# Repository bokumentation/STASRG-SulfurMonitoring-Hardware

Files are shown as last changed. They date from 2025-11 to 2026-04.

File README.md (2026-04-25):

# Init Main Branch

clone this repo with the submodules

```
git clone --recursive https://github.com/bokumentation/STASRG-SulfurMonitoring-Hardware.git
```

## to-do-list

- memisahkan firmware dari repo ini
    - receiver
    - transmitter
    - dummy-uart
- membuat repo sendiri libs untuk kicad dan dibuat submodules

# ghostl + ESP32-S3: The `-mtext-section-literals` Fix

## The Problem

Building ESP-IDF projects that use `ghostl` (via `espsoftwareserial`) for **ESP32-S3** fails with:

```
dangerous relocation: l32r: literal placed after use: .literal._ZNK8delegate...
```

This error **does not** occur on:
- **ESP32** (Xtensa LX6)
- **ESP32-C3** (RISC-V)

And it **does not** occur when building the same code with **Arduino IDE** (arduino-esp32).

## Root Cause

### The `l32r` instruction

The Xtensa architecture has a `l32r` (load literal from PC-relative) instruction used to load 32-bit constants. It loads a value from a **literal pool** — a table of constants placed at a known offset from the current PC. The range of `l32r` is approximately ±256 KB from the instruction.

### IRAM vs Flash on ESP32-S3

Functions marked with `IRAM_ATTR` (as many are in `Delegate.h` and `SoftwareSerial`) are placed in **IRAM** (internal RAM, address range 0x4037xxxx). The normal code (.text) is placed in **flash** (mapped to 0x4200xxxx).

Without `-mtext-section-literals`:
- The compiler places all literal pools in a **centralized .literal section** that lives alongside the flash code (0x4200xxxx)
- Functions in IRAM emit `l32r` instructions pointing to the .literal section in flash
- The distance between IRAM (0x4037xxxx) and the literal pool in flash (0x4200xxxx) exceeds the `l32r` addressing range
- The linker rejects this as a **dangerous relocation**

### Why ESP32 (LX6) is fine

ESP32 uses Xtensa LX6 which defaults to **`-mtext-section-literals` being enabled** in ESP-IDF. So the literal pool is placed inside each text section — no cross-section addressing issue.

### Why ESP32-C3 (RISC-V) is fine

ESP32-C3 is RISC-V, not Xtensa. It has no `l32r` instruction — it uses a different instruction encoding for loading constants. The issue is Xtensa-specific.

### Why Arduino IDE is fine

Arduino IDE (arduino-esp32) sets compile flags differently than ESP-IDF. In particular, it passes `-mtext-section-literals` by default in its platform configuration, avoiding the problem entirely. This is why the same source code that fails in ESP-IDF works in Arduino without any modifications.

## The Fix: `-mtext-section-literals`

Add this to the `CMakeLists.txt` of any component that depends on `ghostl` (e.g. `espsoftwareserial`):

```cmake
target_compile_options(${COMPONENT_LIB} PRIVATE -mtext-section-literals)
```

### How it works

The `-mtext-section-literals` flag tells the Xtensa compiler to place each function's literal pool **inside that function's own text section**, rather than in a centralized `.literal` section. Since the function is in IRAM, its literals go to IRAM too — well within `l32r` range.

### Is it safe?

**Yes, it is completely safe:**

| Concern | Assessment |
|---|---|
| Runtime behavior | No functional change. Literals are read-only constants — being in IRAM vs flash makes no difference to program correctness. |
| Performance | No impact. Constants are read the same way via cache at full speed. |
| IRAM / ISR usage | Preserved. All `IRAM_ATTR` functions continue to work correctly in interrupt context. |
| Binary size | Minor increase (typically < 1 KB). Literal pools may be duplicated across functions instead of shared, but this is negligible. |
| Espressif recommendation | Standard practice. Used by default on ESP32 and in Arduino-esp32. |

## The Previous Attempt: Removing `IRAM_ATTR`

### What we tried

We removed `IRAM_ATTR` from the `operator()` methods in `DelegatePImpl` and `DelegateImpl` classes (the `std::function`/`FUNC` path) in `Delegate.h`.

### Why it worked

Without `IRAM_ATTR`, those functions are placed in flash (0x4200xxxx), right next to the centralized `.literal` section. The `l32r` instruction can reach the literal pool fine — same section, same address space.

### Why we reverted it

Removing `IRAM_ATTR` means those functions **cannot be called from ISR context** — a fundamental requirement for software serial implementations where UART callbacks happen in interrupt context. The `FP` and `FPA` dispatch paths (raw function pointers) retained `IRAM_ATTR`, but the `std::function` path lost ISR safety.

### The better solution

Instead of modifying source code (and compromising ISR safety), we use `-mtext-section-literals` which requires **zero source changes**. All dispatch paths keep their `IRAM_ATTR`, all functions stay ISR-safe, and the linker error is resolved at the compiler flag level.

## Summary

| Build Environment | Default `-mtext-section-literals` | Builds? |
|---|---|---|
| ESP-IDF + ESP32 | ✅ Yes (default) | ✅ |
| ESP-IDF + ESP32-C3 | N/A (RISC-V, no l32r) | ✅ |
| ESP-IDF + ESP32-S3 | ❌ No (default) | ❌ Fails |
| Arduino IDE + ESP32-S3 | ✅ Yes (in platform config) | ✅ |

The fix: add `-mtext-section-literals` to the consumer component's CMakeLists.txt. No source code changes needed.

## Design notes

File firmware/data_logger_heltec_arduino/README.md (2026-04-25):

# Sensor Montoring by STAS-RG
Supported Target: ESP32 | ESP32C3 | ESP32S3

## Daftar Variabel
Tinggal dilanjutkan:

```
live_data.so2_ugm, 
live_data.h2s_ugm, 
live_data.h2s_temp, 
live_data.h2s_hum,
live_data.wind_speed, 
live_data.bus_voltage_v, 
live_data.current_ma
```

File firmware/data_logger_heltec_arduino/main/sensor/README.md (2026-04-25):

Original Example Code from Vendor

```cpp
// anemometer parameters
volatile byte rpmcount;             // hitung signals
volatile unsigned long last_micros;

unsigned long timeold;
unsigned long timemeasure = 10.00;  // detik
int timetoSleep = 1;                // menit
unsigned long sleepTime = 15;       // menit
unsigned long timeNow;
int countThing = 0;
int GPIO_pulse = 14;                // ESP32 = D14
float rpm, rotasi_per_detik;        // rotasi/detik
float kecepatan_kilometer_per_jam;  // kilometer/jam
float kecepatan_meter_per_detik;    //meter/detik
volatile boolean flag = false;

void ICACHE_RAM_ATTR rpm_anemometer()
{
  flag = true;
}

void setup()
{
  pinMode(GPIO_pulse, INPUT_PULLUP);
  digitalWrite(GPIO_pulse, LOW);
  Serial.begin(9600);
  detachInterrupt(digitalPinToInterrupt(GPIO_pulse));                         // memulai Interrupt pada nol
  attachInterrupt(digitalPinToInterrupt(GPIO_pulse), rpm_anemometer, RISING); //Inisialisasi pin interupt
  rpmcount = 0;
  rpm = 0;
  timeold = 0;
  timeNow = 0;
} // end of setup

void loop()
{
  // Cek apakah flag bernilai true, yang menandakan bahwa kondisi tertentu telah terpenuhi
  if (flag == true)
  {
    // Cek apakah waktu sejak deteksi terakhir sudah lebih dari atau sama dengan 5000 mikrodetik (5 milidetik)
    if (long(micros() - last_micros) >= 5000)
    {
      // rJika ya, maka tambahkan satu ke penghitung rpm (pmcount)
      rpmcount++;
      // Perbarui waktu terakhir ketika magnet terdeteksi dengan waktu saat ini
      last_micros = micros();
    }
    // Setelah memproses, setel flag kembali ke false untuk menandakan bahwa kondisi telah ditangani
    flag = false; // reset flag
  }

  if ((millis() - timeold) >= timemeasure * 1000)
  {
    countThing++;
    detachInterrupt(digitalPinToInterrupt(GPIO_pulse));      // Menonaktifkan interrupt saat menghitung
    rotasi_per_detik = float(rpmcount) / float(timemeasure); // rotasi per detik
    //kecepatan_meter_per_detik = rotasi_per_detik; // rotasi/detik sebelum dikalibrasi untuk dijadikan meter per detik
    kecepatan_meter_per_detik = ((-0.0181 * (rotasi_per_detik * rotasi_per_detik)) + (1.3859 * rotasi_per_detik) + 1.4055); // meter/detik sesudah dikalibrasi dan sudah dijadikan meter per detik
    if (kecepatan_meter_per_detik <= 1.5)
    { // Minimum pembacaan sensor kecepatan angin adalah 1.5 meter/detik
      kecepatan_meter_per_detik = 0.0;
    }

    kecepatan_kilometer_per_jam = kecepatan_meter_per_detik * 3.6; // kilometer/jam
    Serial.print("rotasi_per_detik=");
    Serial.print(rotasi_per_detik);
    Serial.print("   kecepatan_meter_per_detik="); // Minimal kecepatan angin yang dapat dibaca sensor adalah 4 meter/detik dan maksimum 30 meter/detik.
    Serial.print(kecepatan_meter_per_detik);
    Serial.print("   kecepatan_kilometer_per_jam=");
    Serial.print(kecepatan_kilometer_per_jam);
    Serial.println("   ");

    if (countThing == 1) // kirim data per 10 detik sekali
    {
      Serial.println("Mengirim data ke server");
      countThing = 0;
    }
    timeold = millis();
    rpmcount = 0;
    attachInterrupt(digitalPinToInterrupt(GPIO_pulse), rpm_anemometer, RISING); // enable interrupt
  }
} // end of loop

```

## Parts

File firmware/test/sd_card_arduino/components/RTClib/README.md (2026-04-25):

# RTClib Documentation

This is a fork of JeeLab's fantastic real time clock library for Arduino.

Works great with Adafruit RTC breakouts:

- [DS3231 Precision RTC](https://www.adafruit.com/product/3013) (breakout) and [Stemma QT version](https://www.adafruit.com/product/5188)
- [PCF8523 RTC](https://www.adafruit.com/product/3295)
- [DS1307 RTC](https://www.adafruit.com/product/3296)

Please note that dayOfTheWeek() ranges from 0 to 6 inclusive with 0 being 'Sunday'.

<!-- START COMPATIBILITY TABLE -->

## Compatibility

MCU                | Tested Works | Doesn't Work | Not Tested  | Notes
------------------ | :----------: | :----------: | :---------: | -----
Atmega328 @ 16MHz  |      X       |             |            |
Atmega328 @ 12MHz  |      X       |             |            |
Atmega32u4 @ 16MHz |      X       |             |            | Use SDA/SCL on pins D3 &amp; D2
Atmega32u4 @ 8MHz  |      X       |             |            | Use SDA/SCL on pins D3 &amp; D2
ESP8266            |      X       |             |            | SDA/SCL default to pins 4 &amp; 5 but any two pins can be assigned as SDA/SCL using Wire.begin(SDA,SCL)
Atmega2560 @ 16MHz |      X       |             |            | Use SDA/SCL on Pins 20 &amp; 21
ATSAM3X8E          |      X       |             |            | Use SDA1 and SCL1
ATSAM21D           |      X       |             |            |
ATtiny85 @ 16MHz   |      X       |             |            |
ATtiny85 @ 8MHz    |      X       |             |            |
Intel Curie @ 32MHz |             |             |     X       |
STM32F2            |             |             |     X       |

  * ATmega328 @ 16MHz : Arduino UNO, Adafruit Pro Trinket 5V, Adafruit Metro 328, Adafruit Metro Mini
  * ATmega328 @ 12MHz : Adafruit Pro Trinket 3V
  * ATmega32u4 @ 16MHz : Arduino Leonardo, Arduino Micro, Arduino Yun, Teensy 2.0
  * ATmega32u4 @ 8MHz : Adafruit Flora, Bluefruit Micro
  * ESP8266 : Adafruit Huzzah
  * ATmega2560 @ 16MHz : Arduino Mega
  * ATSAM3X8E : Arduino Due
  * ATSAM21D : Arduino Zero, M0 Pro
  * ATtiny85 @ 16MHz : Adafruit Trinket 5V
  * ATtiny85 @ 8MHz : Adafruit Gemma, Arduino Gemma, Adafruit Trinket 3V

<!-- END COMPATIBILITY TABLE -->
Adafruit invests time and resources providing this open source code, please support Adafruit and open-source hardware by purchasing products from Adafruit!

# Dependencies
 * [Adafruit BusIO](https://github.com/adafruit/Adafruit_BusIO)

# Contributing

Contributions are welcome! Please read our [Code of Conduct](https://github.com/adafruit/RTClib/blob/master/code-of-conduct.md)
before contributing to help this project stay welcoming.

## Documentation and doxygen
For the detailed API documentation, see https://adafruit.github.io/RTClib/html/index.html
Documentation is produced by doxygen. Contributions should include documentation for any new code added.

Some examples of how to use doxygen can be found in these guide pages:

https://learn.adafruit.com/the-well-automated-arduino-library/doxygen

https://learn.adafruit.com/the-well-automated-arduino-library/doxygen-tips

## Code formatting and clang-format
The code should be formatted according to the [LLVM Coding Standards](https://llvm.org/docs/CodingStandards.html), which is the default of the clang-format tool.  The easiest way to ensure conformance is to [install clang-format](https://llvm.org/builds/) and run

```shell
clang-format -i <source_file>
```

See [Formatting with clang-format](https://learn.adafruit.com/the-well-automated-arduino-library/formatting-with-clang-format) for details.

Written by JeeLabs
MIT license, check license.txt for more information
All text above must be included in any redistribution

To install, use the Arduino Library Manager and search for "RTClib" and install the library.

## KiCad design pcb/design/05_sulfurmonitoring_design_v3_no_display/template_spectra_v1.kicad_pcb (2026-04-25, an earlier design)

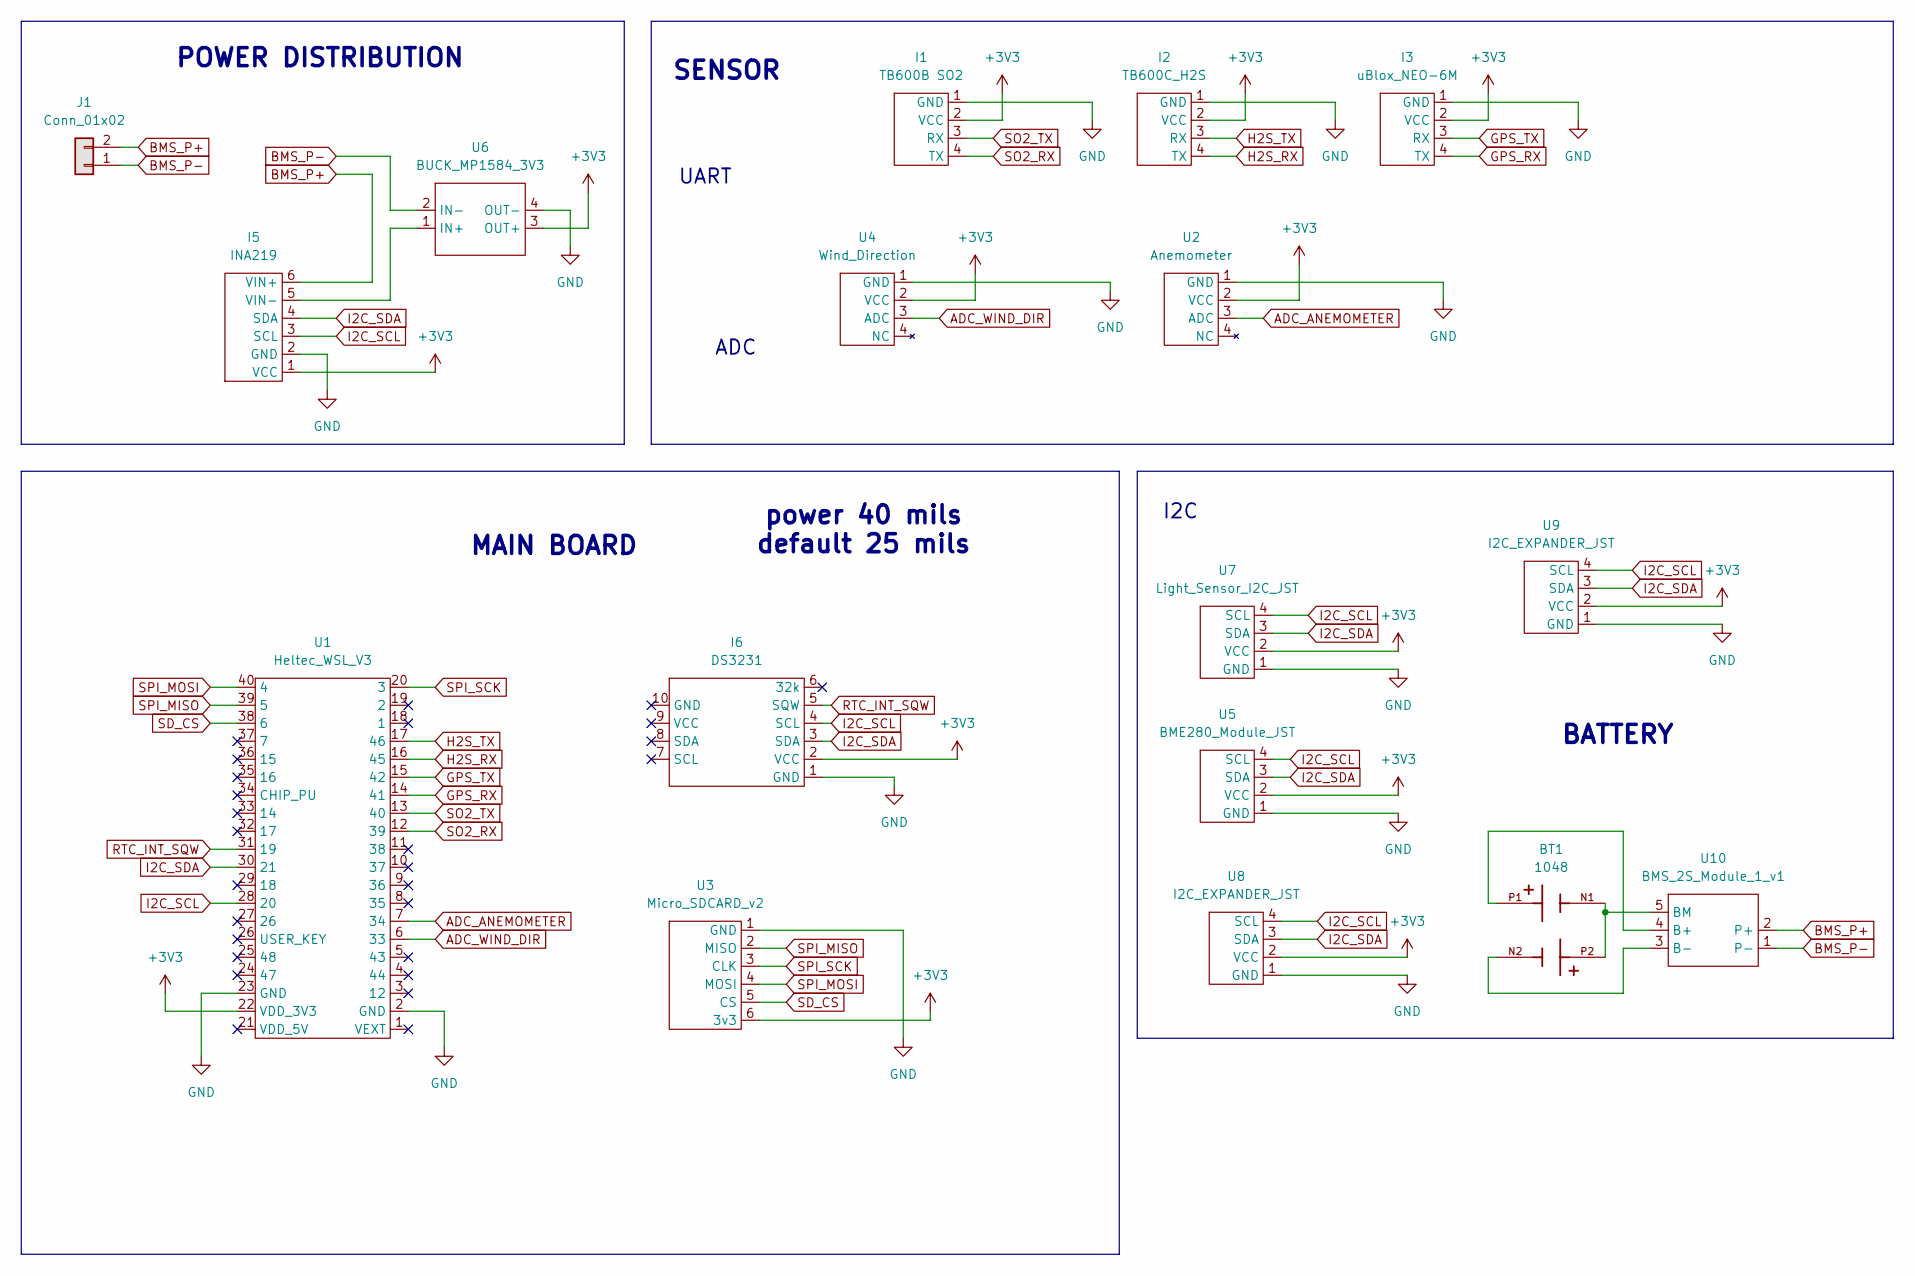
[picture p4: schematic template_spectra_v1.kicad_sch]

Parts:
BT1: 1048; BAT_1048; PARTREV A; DigiKey_Part_Number 36-1048-ND
I1: TB600B SO2; TB600B_SO2_Module
I2: TB600C_H2S; TB600C_H2S_Module
I3: uBlox_NEO-6M; uBlox_NEO-6M_Module_JST
I5: INA219; INA219_Module
I6: DS3231 ; DS3231_Module
J1: Conn_01x02; JST_XH_B2B-XH-A_1x02_P2.50mm_Vertical
U1: Heltec_WSL_V3; Heltec_WSL_V3_Module
U2: Anemometer; STASRG_Anemometer_Module
U3: Micro_SDCARD_v2; Micro_SDCARD_v2_Module
U4: Wind_Direction; STASRG_Wind_Dir_Module
U5: BME280_Module_JST; JST_XH_B4B-XH-A_1x04_P2.50mm_Vertical
U6: BUCK_MP1584_3V3; BUCK_MP1584_3V3_Module
U7: Light_Sensor_I2C_JST; JST_XH_B4B-XH-A_1x04_P2.50mm_Vertical
U8, U9: I2C_EXPANDER_JST; JST_XH_B4B-XH-A_1x04_P2.50mm_Vertical
U10: BMS_2S_Module_1_v1

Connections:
+3V3: I1.2 (VCC), I2.2 (VCC), I3.2 (VCC), I5.1 (VCC), I6.2 (VCC), U1.22 (VDD_3V3), U2.2 (VCC), U3.6 (3v3), U4.2 (VCC), U5.2 (VCC), U6.3 (OUT+), U7.2 (VCC), U8.2 (VCC), U9.2 (VCC)
ADC_ANEMOMETER: U1.7 (34), U2.3 (ADC)
ADC_WIND_DIR: U1.6 (33), U4.3 (ADC)
BMS_P+: I5.6 (VIN+), J1.2, U10.2 (P+)
BMS_P-: J1.1, U6.2 (IN-), U10.1 (P-)
GND: I1.1 (GND), I2.1 (GND), I3.1 (GND), I5.2 (GND), I6.1 (GND), U1.2 (GND), U1.23 (GND), U2.1 (GND), U3.1 (GND), U4.1 (GND), U5.1 (GND), U6.4 (OUT-), U7.1 (GND), U8.1 (GND), U9.1 (GND)
GPS_RX: I3.4 (TX), U1.14 (41)
GPS_TX: I3.3 (RX), U1.15 (42)
H2S_RX: I2.4 (TX), U1.16 (45)
H2S_TX: I2.3 (RX), U1.17 (46)
I2C_SCL: I5.3 (SCL), I6.4 (SCL), U1.28 (20), U5.4 (SCL), U7.4 (SCL), U8.4 (SCL), U9.4 (SCL)
I2C_SDA: I5.4 (SDA), I6.3 (SDA), U1.30 (21), U5.3 (SDA), U7.3 (SDA), U8.3 (SDA), U9.3 (SDA)
unnamed: I5.5 (VIN-), U6.1 (IN+)
unnamed: BT1.P1, U10.4 (B+)
unnamed: BT1.N2, U10.3 (B-)
unnamed: BT1.N1, BT1.P2, U10.5 (BM)
RTC_INT_SQW: I6.5 (SQW), U1.31 (19)
SD_CS: U1.38 (6), U3.5 (CS)
SO2_RX: I1.4 (TX), U1.12 (39)
SO2_TX: I1.3 (RX), U1.13 (40)
SPI_MISO: U1.39 (5), U3.2 (MISO)
SPI_MOSI: U1.40 (4), U3.4 (MOSI)
SPI_SCK: U1.20 (3), U3.3 (CLK)

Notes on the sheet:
BATTERY
UART
I2C
ADC
POWER DISTRIBUTION
power 40 mils default 25 mils
SENSOR
MAIN BOARD

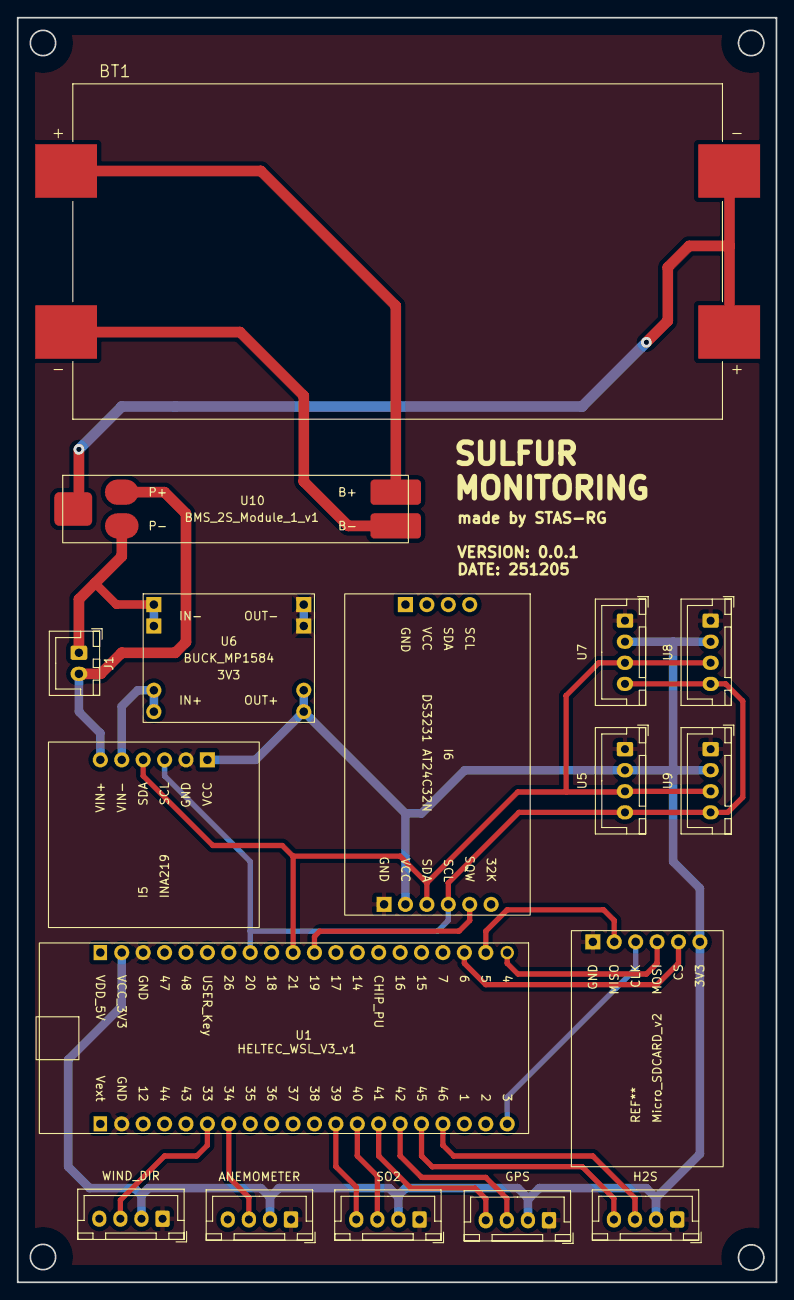
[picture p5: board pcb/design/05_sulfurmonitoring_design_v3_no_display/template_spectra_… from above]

Board: 2 copper layers, 90.0 x 150.0 mm, 17 parts (0 on the bottom side), 23 nets.

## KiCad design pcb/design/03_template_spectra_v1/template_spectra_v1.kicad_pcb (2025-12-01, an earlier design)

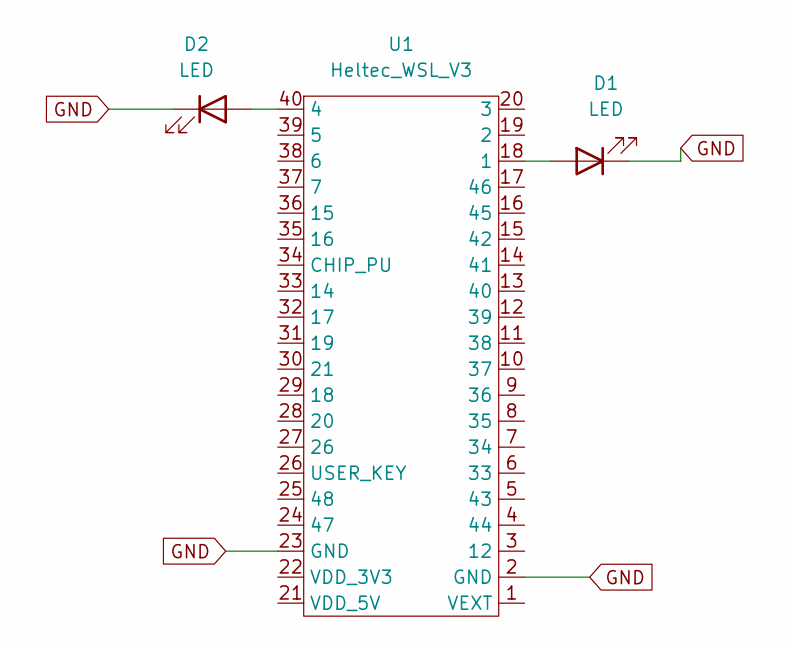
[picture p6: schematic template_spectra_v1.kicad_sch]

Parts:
D1, D2: LED; LED_D5.0mm
U1: Heltec_WSL_V3; Heltec_WSL_V3_v1

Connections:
GND: D1.1 (K), D2.1 (K), U1.2 (GND), U1.23 (GND)
unnamed: D1.2 (A), U1.18 (1)
unnamed: D2.2 (A), U1.40 (4)

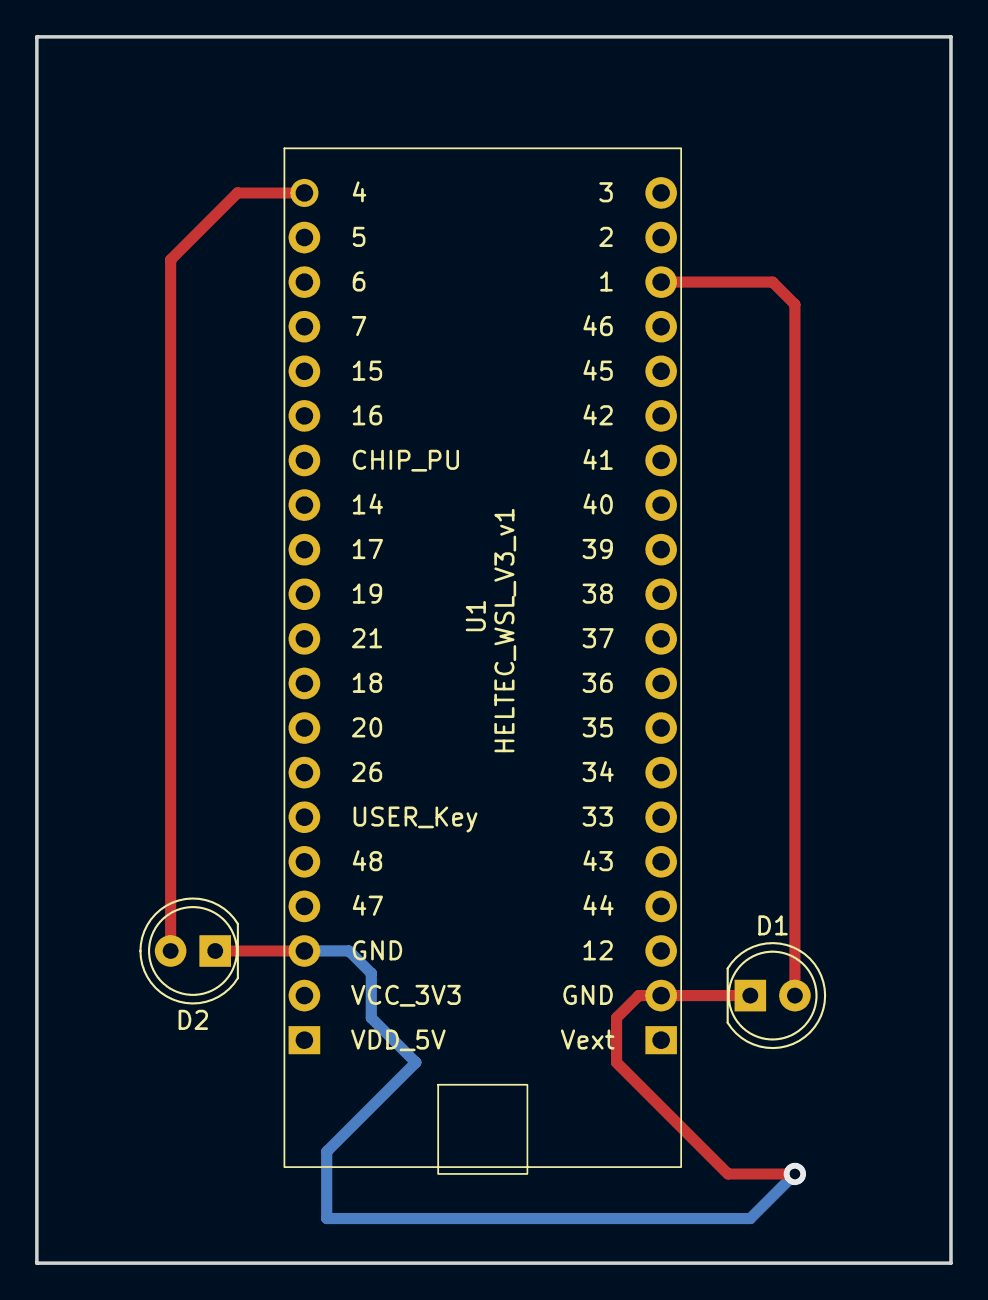
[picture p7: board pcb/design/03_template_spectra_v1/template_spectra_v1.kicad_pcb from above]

Board: 2 copper layers, 52.1 x 69.8 mm, 3 parts (0 on the bottom side), 3 nets.

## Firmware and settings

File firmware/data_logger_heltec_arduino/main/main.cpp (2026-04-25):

// main.cpp
// --- SYSTEM INCLUDE ----
#include <Arduino.h>
#include <Wire.h>
#include <esp32-hal.h>
#include <freertos/idf_additions.h>
#include <freertos/projdefs.h>

// --- USER INCLUDE ----
#include "board_pins.h"  // Definisi Pin yang dipakai
#include "sensor_task.h" // Header kode sensor
#include "shared_data.h" // Data sensor bersama

// --- FUNGSI UTAMA ESP-IDF ---
extern "C" void app_main()
{
    initArduino();
    Serial.begin(115200);                 // Memastikan UART USB Serial Monitor terinisialisasi
    Wire.begin(PIN_I2C_SDA, PIN_I2C_SCL); // Inisialisasi I2C

    // 1. Membuat Task fungsi membaca sensor
    xTaskCreate(sensor_reading, "Gas_Sensor_Task", 4096, NULL, SENSOR_TASK_PRIORITY, NULL);

    // 2. Membuat Task fungsi membaca anemometer
    xTaskCreate(anemometer_task, "Anemometer_Task", 2048, ANEMOMETER_PIN_CFG, SENSOR_TASK_PRIORITY + 1, NULL);

    // 3. Membuat Task fungsi membaca battery
    xTaskCreate(batteryTask, "Battery_Task", 4096, NULL, 2, NULL);

    // 4. Kodingan LoRA di mulai dari sini

    while (1) {
        // Kodingan LoRa untuk mengirim data atau menerima

        // Print ke serial monitor dengan aman
        if (xSemaphoreTake(data_mutex, pdMS_TO_TICKS(10))) {
            Serial.printf("%.3f,%.3f,%.2f,%.2f,%.2f,%.2f,%.1f\n", live_data.so2_ugm, live_data.h2s_ugm, live_data.h2s_temp, live_data.h2s_hum,
                          live_data.wind_speed, live_data.bus_voltage_v, live_data.current_ma);

            xSemaphoreGive(data_mutex);
        }

        delay(1000); // Delay 1 detik untuk menghindari flooding serial monitor
        vTaskDelay(pdMS_TO_TICKS(1));
    }
}

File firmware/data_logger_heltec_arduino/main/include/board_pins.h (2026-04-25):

// board_pins.h
#pragma once

// BOARDS PIN DEFINITON
// SUPPORTED: ESP32 | ESP32C3 SUPERMINI | ESP32S3 DEVKITC | HELTEC WIRELESS STICK LITE V3

#include <hal/gpio_hal.h>
#include <hal/uart_types.h>
#include <sdkconfig.h>

// --- Define Board Type START HERE ---
// #define BOARD_DEVKITC_ESP32S3_V1
#define BOARD_HELTEC_WSL_ESP32S3_V3
// --- Define Board Type END HERE -----

#ifdef CONFIG_IDF_TARGET_ESP32
    #define ANEMOMETER_ADC_PIN 32
    #define ANEMOMETER_TAG     "ANEMOMETER"

    #define H2S_UART_PORT     UART_NUM_1
    #define PIN_SENSOR_H2S_RX 26
    #define PIN_SENSOR_H2S_TX 27
    #define SENSOR_H2S_TAG    "TB600B_H2S"

    #define SO2_UART_PORT     UART_NUM_2
    #define PIN_SENSOR_SO2_RX 16
    #define PIN_SENSOR_SO2_TX 17
    #define SENSOR_SO2_TAG    "TB600B_SO2"

#elif defined(CONFIG_IDF_TARGET_ESP32C3)
    #define ANEMOMETER_ADC_PIN 1
    #define ANEMOMETER_TAG     "ANEMOMETER"

    #define SENSOR_H2S_UART_PORT UART_NUM_0
    #define PIN_SENSOR_H2S_RX    9
    #define PIN_SENSOR_H2S_TX    10
    #define SENSOR_H2S_TAG       "TB600B_H2S"

    #define SENSOR_SO2_UART_PORT UART_NUM_1
    #define PIN_SENSOR_SO2_RX    20
    #define PIN_SENSOR_SO2_TX    21
    #define SENSOR_SO2_TAG       "TB600B_SO2"

    #define PIN_I2C_SCL 3
    #define PIN_I2C_SDA 4

#elif defined(CONFIG_IDF_TARGET_ESP32S3)
    #if defined(BOARD_DEVKITC_ESP32S3_V1)
        #define ANEMOMETER_ADC_PIN GPIO_NUM_3
        #define ANEMOMETER_TAG     "ANEMOMETER"

        #define SO2_UART_PORT UART_NUM_0
        #define SO2_RX_PIN    GPIO_NUM_44
        #define SO2_TX_PIN    GPIO_NUM_43
        #define SO2_LOG_TAG   "TB600B_SO2"

        #define H2S_UART_PORT UART_NUM_1
        #define H2S_RX_PIN    GPIO_NUM_17
        #define H2S_TX_PIN    GPIO_NUM_18
        #define H2S_LOG_TAG   "TB600B_H2S"

    #elif defined(BOARD_HELTEC_WSL_ESP32S3_V3)
        // - 0. LoRa SX1262 PINS (FIXED by Heltec WSL v3) ---
        // These pins are hardwired to the onboard HELTEC LoRa module.
        #define PIN_LORA_NSS  8
        #define PIN_LORA_SCK  9
        #define PIN_LORA_MISO 10
        #define PIN_LORA_MOSI 11
        #define PIN_LORA_RST  12
        #define PIN_LORA_BUSY 13
        #define PIN_LORA_DIO1 14

        // - 1. SPI BUS (SD Card and W5500 Ethernet) ---
        // -- 1.1 Dedicated SPI bus (SPI3/VSPI) using accessible GPIO pins
        #define PIN_SPI3_SCK  3
        #define PIN_SPI3_MOSI 4
        #define PIN_SPI3_MISO 5
        // -- 1.2 Select Pin for SPI3 connected modules
        #define PIN_SD_CS     6
        #define PIN_W5500_CS  2

        // - 2. I2C BUS (RTC, OLED, INA219 x2) ---
        #define PIN_I2C_SCL   20
        #define PIN_I2C_SDA   21

        #define I2C_MASTER_SCL_IO PIN_I2C_SCL
        #define I2C_MASTER_SDA_IO PIN_I2C_SDA

        #define I2C_MASTER_NUM              I2C_NUM_0
        #define I2C_MASTER_FREQ_HZ          400000

        // -- 2.1. I2C ADDRESS for the modules ---
        // --- 2.1.1. I2C MODULE: REALTIME CLOCK - DS3231 ---
        #define RTC_TAG                     "DS3231_RTC"
        #define PIN_RTC_INT_SQW             19
        #define I2C_HW_ADDR_RTC_DS3231      0x68
        #define I2C_HW_ADDR_RTC_AT24C32     0x57

        // --- 2.1.2. I2C MODULE: DISPLAY - SSD1306 ---
        #define DISPLAY_TAG                 "SSD1306_DISPLAY"
        #define I2C_HW_ADDR_DISPLAY_SSD1306 0x3C
        // --- 2.1.3. I2C MODULE: DEVICE ENERGY MONITOR - INA219 ---
        #define BAT_DEVICE_MONITORING_TAG   "INA219_DEVICE_MONITOR_1"
        #define I2C_HW_ADDR_SENSOR_INA219_1 0x40
        // --- 2.1.4. I2C MODULE: CHARGING MONITOR - INA219 ---
        #define BAT_CHARGER_MONITORING_TAG "INA219_CHARGER_MONITOR_2"
        #define I2C_HW_ADDR_SENSOR_INA219_2 0x41

        // - 3. UART PERIPHERALS (Sensors and GPS) ---
        // -- 3.1. UART 1 (Hardware) - TB600B H2S Sensor: ✅ TESTED
        #define SENSOR_H2S_UART_PORT      UART_NUM_1
        #define SENSOR_H2S_TAG            "TB600B_H2S"
        #define PIN_SENSOR_H2S_TX         46 // WHITE
        #define PIN_SENSOR_H2S_RX         45 // YELLOW
        // -- 3.2. UART 2 (Hardware) - TB600B SO2 Sensor: ✅ TESTED
        #define SENSOR_SO2_UART_PORT      UART_NUM_2
        #define SENSOR_SO2_TAG            "TB600B_SO2"
        #define PIN_SENSOR_SO2_TX         40 // WHITE
        #define PIN_SENSOR_SO2_RX         39 // YELLOW
        // -- 3.3. UART GPS Module uses Software Serial: UNTESTED
        #define PIN_SENSOR_GPS_TX         42
        #define PIN_SENSOR_GPS_RX         41

        // - 4. ANALOG (ADC) Inputs (Wind Speed and Sirection) ---
        #define PIN_SENSOR_ANEMOMETER_ADC 34 // ADC1_CH3: UNTESTED
        #define ANEMOMETER_TAG     "ANEMOMETER"
        
        #define PIN_SENSOR_WIND_DIR_TX   33 // ADC1_CH4: UNTESTED
        #define PIN_SENSOR_WIND_DIR_RX   12 // ADC1_CH4: UNTESTED
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

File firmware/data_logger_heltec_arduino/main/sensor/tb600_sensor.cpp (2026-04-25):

// tb600_sensor.cpp
#include "tb600_sensor.h"
#include "driver/uart.h"
#include "esp_log.h"
#include "tb600_sensor_cmd.h"
#include <board_pins.h>

static esp_err_t tb600b_wait_for_data(uart_port_t uart_num, const char *tag);

void tb600b_init_uart(uart_port_t uart_num, int tx_pin, int rx_pin, const char *tag)
{
    const uart_config_t uart_config = {
        .baud_rate = 9600,
        .data_bits = UART_DATA_8_BITS,
        .parity = UART_PARITY_DISABLE,
        .stop_bits = UART_STOP_BITS_1,
        .flow_ctrl = UART_HW_FLOWCTRL_DISABLE,
        .rx_flow_ctrl_thresh = 122,
        .source_clk = UART_SCLK_DEFAULT,
    }; // Missing 'flag' initializer but it not needed.

    ESP_ERROR_CHECK(uart_driver_install(uart_num, RX_BUF_SIZE * 2, 0, 0, NULL, 0));
    ESP_ERROR_CHECK(uart_param_config(uart_num, &uart_config));
    ESP_ERROR_CHECK(uart_set_pin(uart_num, tx_pin, rx_pin, UART_PIN_NO_CHANGE, UART_PIN_NO_CHANGE));

    ESP_LOGI(tag, "Initialize...");
    vTaskDelay(pdMS_TO_TICKS(100));
}

static esp_err_t tb600b_wait_for_data(uart_port_t uart_num, const char *tag)
{
    size_t length = 0;
    const int max_wait_ms = 500;
    const int delay_step_ms = 5;

    for (int elapsed = 0; elapsed < max_wait_ms; elapsed += delay_step_ms) {
        if (uart_get_buffered_data_len(uart_num, &length) != ESP_OK) {
            return ESP_FAIL;
        }

        if (length > 0) {
            return ESP_OK;
        }

        vTaskDelay(pdMS_TO_TICKS(delay_step_ms));
    }
    ESP_LOGW(tag, "No response data detected in buffer after %d ms.", max_wait_ms);
    return ESP_ERR_TIMEOUT;
}

esp_err_t tb600b_read_combined_data(uart_port_t uart_num, const uint8_t *command, size_t commandSize, tb600b_combined_data_t *data_out)
{
    const char *tag = (uart_num == UART_NUM_1) ? SENSOR_H2S_TAG : SENSOR_SO2_TAG;
    const int max_sync_attempts = TB600B_RESPONSE_LENGTH + 2;
    uint8_t responseData[TB600B_RESPONSE_LENGTH];
    int bytesRead = 0;

    if (!data_out) {
        ESP_LOGE(tag, "Output data structure pointer is NULL.");
        return ESP_ERR_INVALID_ARG;
    }

    // 1. Flush and Send Command
    uart_flush(uart_num);
    if (uart_write_bytes(uart_num, command, commandSize) != commandSize) {
        return ESP_FAIL;
    }
    vTaskDelay(pdMS_TO_TICKS(50)); // Sensor internal processing delay

    // 2. Adaptive Wait for First Byte
    if (tb600b_wait_for_data(uart_num, tag) != ESP_OK) {
        return ESP_ERR_TIMEOUT; // Exit immediately on total comms failure
    }

    // 3. Synchronization Loop
    for (int sync_count = 0; sync_count < max_sync_attempts; sync_count++) {
        // Read the full expected frame length with a short timeout
        bytesRead = uart_read_bytes(uart_num, responseData, TB600B_RESPONSE_LENGTH, pdMS_TO_TICKS(100));

        if (bytesRead == TB600B_RESPONSE_LENGTH) {
            if (responseData[0] == TB600B_RESPONSE_HEADER_BYTE1 && responseData[1] == TB600B_RESPONSE_HEADER_BYTE2) {
                // SUCCESS: Valid frame read. Log and break loop for parsing.
                ESP_LOG_BUFFER_HEXDUMP(tag, responseData, bytesRead, ESP_LOG_DEBUG);
                goto parse_data;
            }
            else {
                // MISALIGNMENT: Attempt to re-sync
                ESP_LOGW(tag, "Malformed header found. Attempting re-sync.");

                // Try to find header mid-frame and push remaining data back
                for (int i = 1; i < bytesRead - 1; i++) {
                    if (responseData[i] == 0xFF && responseData[i + 1] == 0x87) {
                        uart_write_bytes(uart_num, (const char *)&responseData[i], TB600B_RESPONSE_LENGTH - i);
                        vTaskDelay(pdMS_TO_TICKS(10));
                        goto continue_sync_loop; // Skip to next loop iteration
                    }
                }

                // If no header found mid-frame, flush and rely on next read
                uart_flush(uart_num);
                vTaskDelay(pdMS_TO_TICKS(10));
            }
        }
        else if (bytesRead > 0 && bytesRead < TB600B_RESPONSE_LENGTH) {
            // Partial read: likely noise. Flush and retry.
            ESP_LOGW(tag, "Partial response (%d bytes). Flushing and retrying.", bytesRead);
            uart_flush(uart_num);
            vTaskDelay(pdMS_TO_TICKS(10));
        }
        else {
            // Timeout (bytesRead == 0) after waiting.
            ESP_LOGE(tag, "Timeout during frame read.");
            break; // Exit loop, fail the function
        }

    continue_sync_loop:; // Label for continue/retry logic
    }

    // --- 4. FAILURE EXIT ---
    ESP_LOGE(tag, "Failed to synchronize frame header after %d attempts.", max_sync_attempts);
    data_out->temperature_c = data_out->humidity_perc = data_out->gas_ugm3 = 0.0f;
    return ESP_ERR_TIMEOUT;

// --- 5. SUCCESS PARSING ---
parse_data:
    // Parse gas concentration (ug/m³) from bytes 2 and 3
    uint16_t rawGasUg = (uint16_t)((responseData[2] << 8) | responseData[3]);
    data_out->gas_ugm3 = (float)rawGasUg;

    // Parse Temperature from bytes 8 and 9
    int16_t rawTemperature = (int16_t)((responseData[8] << 8) | responseData[9]);
    data_out->temperature_c = (float)rawTemperature / 100.0f;

    // Parse Humidity from bytes 10 and 11
    uint16_t rawHumidity = (uint16_t)((responseData[10] << 8) | responseData[11]);
    data_out->humidity_perc = (float)rawHumidity / 100.0f;
    
    // BELUM DITEST
    // data_out->success = true;

    vTaskDelay(pdMS_TO_TICKS(100));
    return ESP_OK;
}

tb600b_combined_data_t tb600b_get_data_safe(uart_port_t uart_num, const uint8_t *command, size_t commandSize)
{
    tb600b_combined_data_t data = {0, 0, 0, 0};                                       // Zero-initialize the entire structure (T=0, H=0, Gas=0, Success=false)
    const char *tag = (uart_num == UART_NUM_1) ? "SENSOR_H2S_TAG" : "SENSOR_SO2_TAG"; // Placeholder for tag determination

    esp_err_t err = tb600b_read_combined_data(uart_num, command, commandSize, &data);

    if (err != ESP_OK) {
        ESP_LOGE(tag, "Failed to read data from sensor (Error: 0x%X). Returning zeroed structure.", err);
    }
    else {
        data.success = true;
    }

    return data;
}
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

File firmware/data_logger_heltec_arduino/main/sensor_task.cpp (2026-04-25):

// SENSOR_TASK.CPP
/*
 * =====================================
 * === IMPLEMENTASI PEMBACAAN SENSOR ===
 * =====================================
 *
 * Berhasil diuji:
 * TB600B_SO2:  UART    ✅
 * TB600C_H2S:  UART    ✅
 * ANEMOMETER:  ADC     ✅
 * INA219:      I2C     ✅
 *
 * Belum diuji:
 * BME280:      I2C     ❌
 * RTC_DS3231:  I2C     ❌
 * UBLOX NEO:   UART    ❌
 * WIND DIR:    UART    ❌
 */

// --- SYSTEM INCLUDE ---
#include <Arduino.h>
#include <HardwareSerial.h>
#include <cstdio>
#include <esp_log.h>

// --- USER LIBRARIES ---
#include <Adafruit_BME280.h> // BME280 (ATM Pressure)
#include <RTClib.h>          // RTC DS3231 (Realtime Clock)
#include <RadioLib.h>        // SX1262 (L O R A Communication)
#include <SoftwareSerial.h>  // Emulated Software Serial (arduino-esp32 aslinya tidak support SoftwareSerial)
#include <TinyGPSPlus.h>     // GPS uBlox Neo

// --- USER INCLUDE ---
#include "board_pins.h"
#include "sensor/anemometer.h"   // Anemometer
#include "sensor/tb600_sensor.h" // tb600 sensor untuk SO2 dan H2S
#include "shared_data.h"         // Data versi MUTEX supaya tidak terjadi Race Condition

// --- USER DEFINE ---

// Data mutex untuk menghindari race condition dengan task lain
// Mutex digunakan untuk mengamankan akses ke data live_data
// karena data ini diakses oleh beberapa task (sensor_reading, anemometer_task, batteryTask)
SemaphoreHandle_t data_mutex = xSemaphoreCreateMutex();

// Inisialisasi objek untuk menyimpan data dari sensor
sensor_output_t live_data = {.so2_ppm = 0.0,
                             .so2_ugm = 0.0,
                             .h2s_ppm = 0.0,
                             .h2s_ugm = 0.0,
                             .h2s_temp = 0.0,
                             .h2s_hum = 0.0,
                             .wind_speed = 0.0,
                             .bus_voltage_v = 0.0,
                             .current_ma = 0.0};

// --- Task 1: Pembacaan sensor TB6000
#define UART_SENSOR_READ_INTERVAL_MS 2000 // Interval pembacaan sensor dalam milidetik

// Inisialisasi objek untuk menyimpan data dari sensor h2s dan so2
tb600b_combined_data_t h2s_data{}; // Struct h2s
tb600b_combined_data_t so2_data{}; // Struct so2

// Pembacaan sensor TB6000
void sensor_reading(void *pvParameters)
{
    // Inisialisasi UART untuk H2S
    tb600b_init_uart(SENSOR_H2S_UART_PORT, PIN_SENSOR_H2S_TX, PIN_SENSOR_H2S_RX, SENSOR_H2S_TAG);

    // Inisialisasi UART untuk SO2
    tb600b_init_uart(SENSOR_SO2_UART_PORT, PIN_SENSOR_SO2_TX, PIN_SENSOR_SO2_RX, SENSOR_SO2_TAG);

    while (1) {
        // Membaca sensor melalui UART1 dan UART2
        tb600b_read_combined_data(SENSOR_H2S_UART_PORT, CMD_GET_COMBINED_DATA, sizeof(CMD_GET_COMBINED_DATA), &h2s_data);
        tb600b_read_combined_data(SENSOR_SO2_UART_PORT, CMD_GET_COMBINED_DATA, sizeof(CMD_GET_COMBINED_DATA), &so2_data);

        // Contoh konversi dari ug/m³ ke ppm
        // live_data.h2s_ppm = tb600b_convert_ugm3_to_ppm(h2s_data.gas_ugm3, h2s_data.temperature_c, M_W_H2S); // H2S: 34.08 g/mol
        // live_data.h2s_ugm = h2s_data.gas_ugm3;

        // live_data.so2_ppm = tb600b_convert_ugm3_to_ppm(so2_data.gas_ugm3, so2_data.temperature_c, M_W_SO2); // SO2: 64.06 g/mol
        // live_data.so2_ugm = so2_data.gas_ugm3;

        // UPDATE STRUKTUR DATA SHARED
        if (xSemaphoreTake(data_mutex, pdMS_TO_TICKS(100))) {
            live_data.h2s_ugm = h2s_data.gas_ugm3;
            live_data.so2_ugm = so2_data.gas_ugm3;
            live_data.h2s_temp = h2s_data.temperature_c;
            live_data.h2s_hum = h2s_data.humidity_perc;
            xSemaphoreGive(data_mutex);
        }

        // Delay untuk menghindari pembacaan terlalu cepat
        // Interval pembacaan sensor diatur sesuai dengan kebutuhan
        vTaskDelay(pdMS_TO_TICKS(UART_SENSOR_READ_INTERVAL_MS));
    }
}

// --- Task 2: Anemometer Polling (Non-Blocking) ---
#define ANEMOMETER_MEASUREMENT_INTERVAL_SEC 10
#define ANEMOMETER_POLL_MS                  5

anemometer_handle_t g_anemometer_handle = NULL;
anemometer_data_t anem_data{}; // Inisialisasi objek struct untuk menyimpan data nanemometer

// Anemometer Task untuk membaca kecepatan angin
void anemometer_task(void *pvParameters)
{
    int pin = (int)pvParameters;
    g_anemometer_handle = anemometer_create(pin, ANEMOMETER_MEASUREMENT_INTERVAL_SEC);

    if (g_anemometer_handle == NULL) {
        ESP_LOGE(ANEMOMETER_TAG, "FATAL: Failed to allocate context!");
        vTaskDelete(NULL);
        return;
    }

    anemometer_begin(g_anemometer_handle);
    ESP_LOGI(ANEMOMETER_TAG, "Init OK. Measuring every %u seconds.", ANEMOMETER_MEASUREMENT_INTERVAL_SEC);

    while (1) {
        if (anemometer_read_speed(g_anemometer_handle, &anem_data)) {
            if (xSemaphoreTake(data_mutex, pdMS_TO_TICKS(50))) {
                live_data.wind_speed = anem_data.wind_speed_mps;
                xSemaphoreGive(data_mutex);
            }
        }

        vTaskDelay(pdMS_TO_TICKS(ANEMOMETER_POLL_MS));
    }
}

// --- Task 3: Pembaca Tegangan dan Arus Baterai (INA219) ---
#include "Adafruit_INA219.h"
Adafruit_INA219 ina219_device(I2C_HW_ADDR_SENSOR_INA219_2);

// Pembaca Tegangan dan Arus Baterai (INA219)
void batteryTask(void *pvParameters)
{
    // Error handling jika I2C tidak berhasil diinisialisasi
    if (!Wire.begin(PIN_I2C_SDA, PIN_I2C_SCL)) {
        ESP_LOGE(BAT_DEVICE_MONITORING_TAG, "I2C Begin Failed");
        vTaskDelete(NULL);
    }

    // Error handling jika INA219 tidak berhasil diinisialisasi
    if (!ina219_device.begin(&Wire)) {
        ESP_LOGE(BAT_DEVICE_MONITORING_TAG, "Couldn't find INA219 chip");
    }

    ina219_device.setCalibration_32V_2A(); // Kalibrasi INA219 untuk 32V dan 2A

    while (1) {
        // Parameter penting
        float shuntvoltage = ina219_device.getShuntVoltage_mV();
        float busvoltage = ina219_device.getBusVoltage_V();

        // Perhitungan arus dan tegangan
        float current_mA = ina219_device.getCurrent_mA();
        float loadvoltage = busvoltage + (shuntvoltage / 1000);

        // Forward data ke live_data
        if (xSemaphoreTake(data_mutex, pdMS_TO_TICKS(50))) {
            live_data.bus_voltage_v = loadvoltage;
            live_data.current_ma = current_mA;
            xSemaphoreGive(data_mutex);
        }

        vTaskDelay(pdMS_TO_TICKS(1000));
    }
}

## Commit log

2025-11-27 added new arduino as components
2025-11-28 Create Symbols
    Symbols and Footprints
2025-11-28 Update and rename pcb/ina219.kicad_sym to pcb/symbols/ina219.kicad_sym
2025-11-28 Update and rename pcb/rtc_ds3231 .kicad_sym to pcb/symbols/rtc_ds3231 .kicad_sym
2025-11-28 Update and rename pcb/spi sd card.kicad_sym to pcb/symbols/spi sd card.kicad_sym
2025-11-28 Update and rename pcb/ssd1306 .kicad_sym to pcb/symbols/ssd1306 .kicad_sym
2025-11-28 Update and rename pcb/tb600b.kicad_sym to pcb/symbols/tb600b.kicad_sym
2025-11-28 Update and rename pcb/tb600c.kicad_sym to pcb/symbols/tb600c.kicad_sym
2025-11-28 Update and rename pcb/wind direction.kicad_sym to pcb/symbols/wind direction.kicad_sym
2025-11-28 Update and rename pcb/wsl_v3.kicad_sym to pcb/symbols/wsl_v3.kicad_sym
2025-12-01 added module references
    [03_sulfur_monitoring_references.kicad_pcb, 03_sulfur_monitoring_references.kicad_sch]
2025-12-01 Added PCB Module References
    [03_sulfur_monitoring_references.kicad_pcb, 03_sulfur_monitoring_references.kicad_sch]
2025-12-01 edit some footprint
    [03_sulfur_monitoring_references.kicad_pcb, 03_sulfur_monitoring_references.kicad_sch]
2025-12-01 renamed symbol to libraries
    [03_sulfur_monitoring_references.kicad_pcb, 03_sulfur_monitoring_references.kicad_sch]
2025-12-01 deleted footprint folder
2025-12-01 renamed and added test library
    [03_sulfur_monitoring_references.kicad_pcb, 03_sulfur_monitoring_references.kicad_sch, 05_test_for_num_04.kicad_pcb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]
2025-12-01 added new design
    [template_spectra_v1.kicad_pcb, template_spectra_v1.kicad_sch]
2025-12-01 added revision
    [template_spectra_v1.kicad_pcb, template_spectra_v1.kicad_sch]
2025-12-02 update design
    [template_spectra_v1.kicad_pcb]
2025-12-05 update drc
    [template_spectra_v1.kicad_pcb, template_spectra_v1.kicad_sch]
2025-12-07 new design
    [template_spectra_v1.kicad_pcb, template_spectra_v1.kicad_sch]
2025-12-08 added output gerber
    [05_sulfurmonitoring_design_v4_no_display-B_Cu.gbr, 05_sulfurmonitoring_design_v4_no_display-B_Mask.gbr, 05_sulfurmonitoring_design_v4_no_display-B_Silkscreen.g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]
2025-12-09 added sensor_task
2025-12-17 Update for esp32s3 target
    Added ANEMOMETER_TAG
    Using PIN_SENSOR_ANEMOMETER_ADC
2026-04-25 edit pcb
    [05_sulfurmonitoring_design_v4_no_display-B_Cu.gbr, 05_sulfurmonitoring_design_v4_no_display-B_Mask.gbr, 05_sulfurmonitoring_design_v4_no_display-B_Silkscreen.g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]
